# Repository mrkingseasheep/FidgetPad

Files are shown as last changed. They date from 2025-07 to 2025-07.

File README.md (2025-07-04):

# FidgetPad V2.1

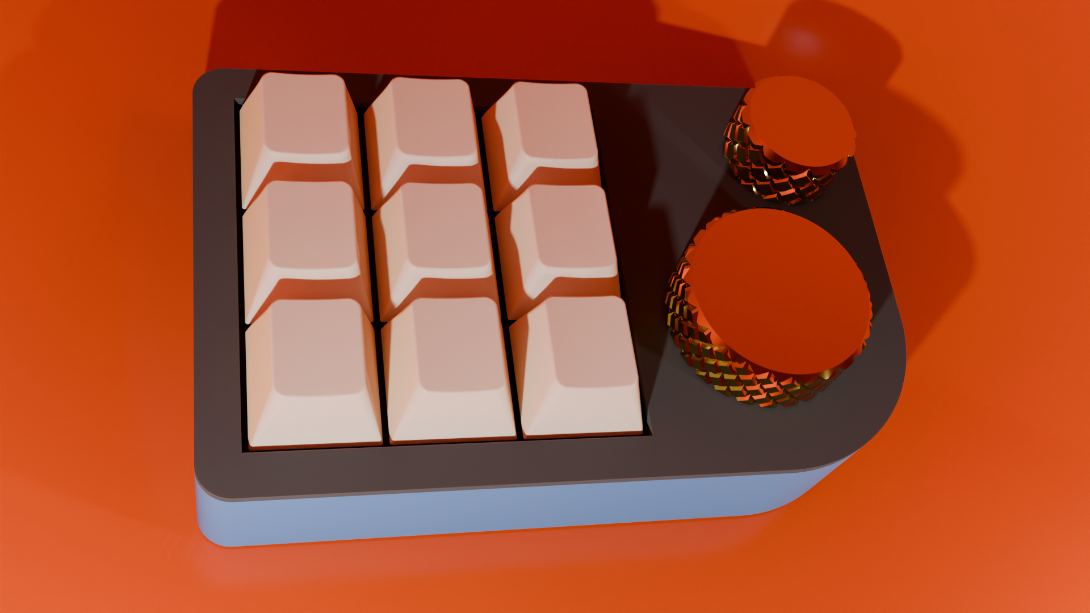
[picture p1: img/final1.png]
Render 1


Keyboards are flat. Flat is boring. Why not add some turny things?

This is a 3x3 macropad with 2 rotary encoders that originally had an OLED screen before I realized that I could trade it in for a 3x3 keyboard instead of a 1x3 row.
It's meant to supplement my normal shitty keyboard which lacks a volume knob, something that I sorely miss.
Btw the git commit history is so empty because I had some large .blend files in my last repo that I just couldn't get rid of (so GitHub didn't let me push) :P

## BOM

| Item | QNT |
| --- | --- |
| MX Style Switchs | 9 |
| Keycaps | 9 |
| 1N4148 Diode | 9 |
| EC11 Encoders | 2 |
| XIAO RP2040 | 1 |
| M3 Screws | 2 |
| M3 Heat Insert | 2 |
| PCB | 1 |
| Case | 1 |

## Images

It took a comical amount of time for me to realize that my schematic could be neat. Don't look at V1. Also turns out I didn't need pullup resistors on every single pin. Neat!
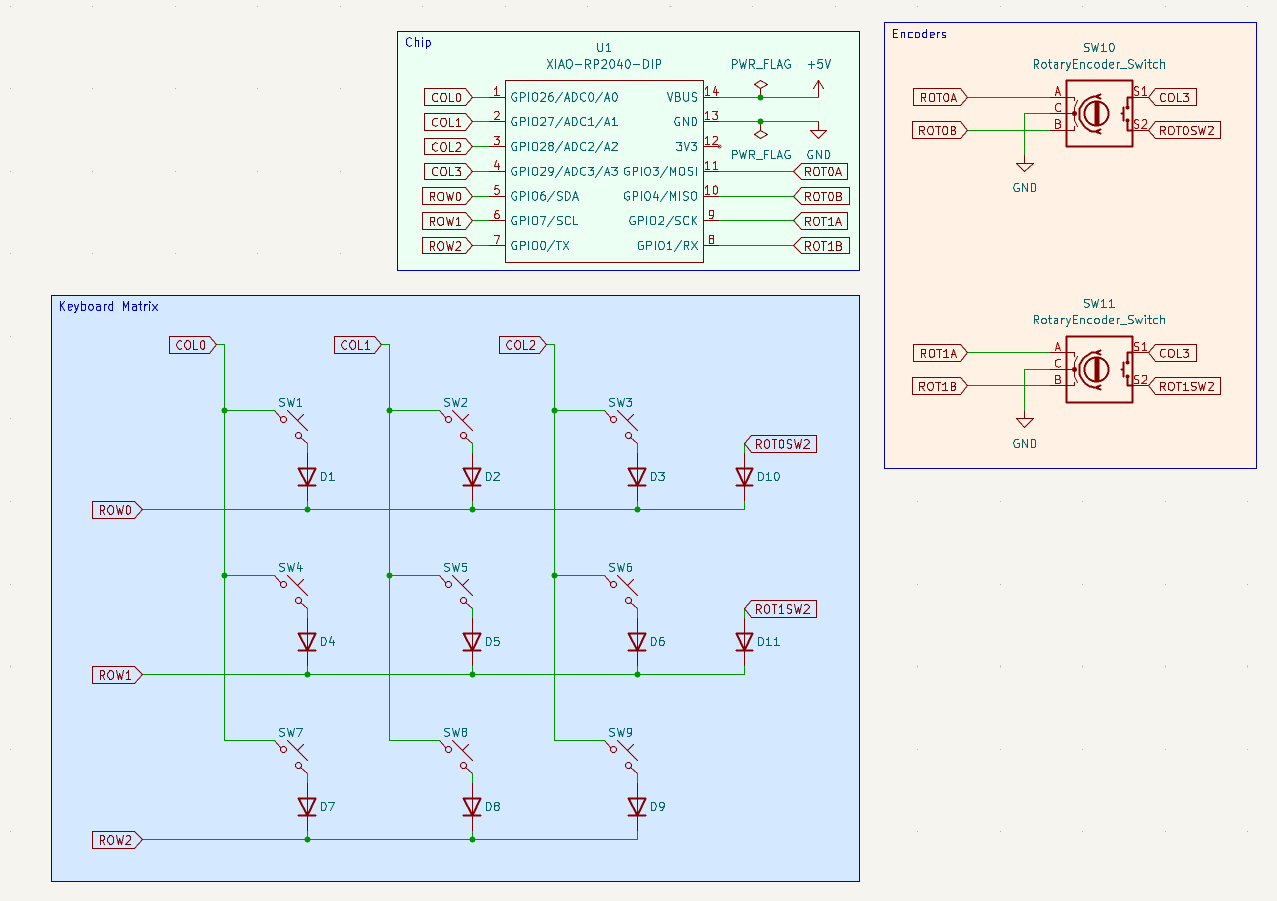
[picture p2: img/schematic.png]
Schematic


There are breakout pins for GND, +5V and +3V3 but I'm not sure if I want to use them. I put them there just in case I wanted to add some jank LEDs at any point in the future.
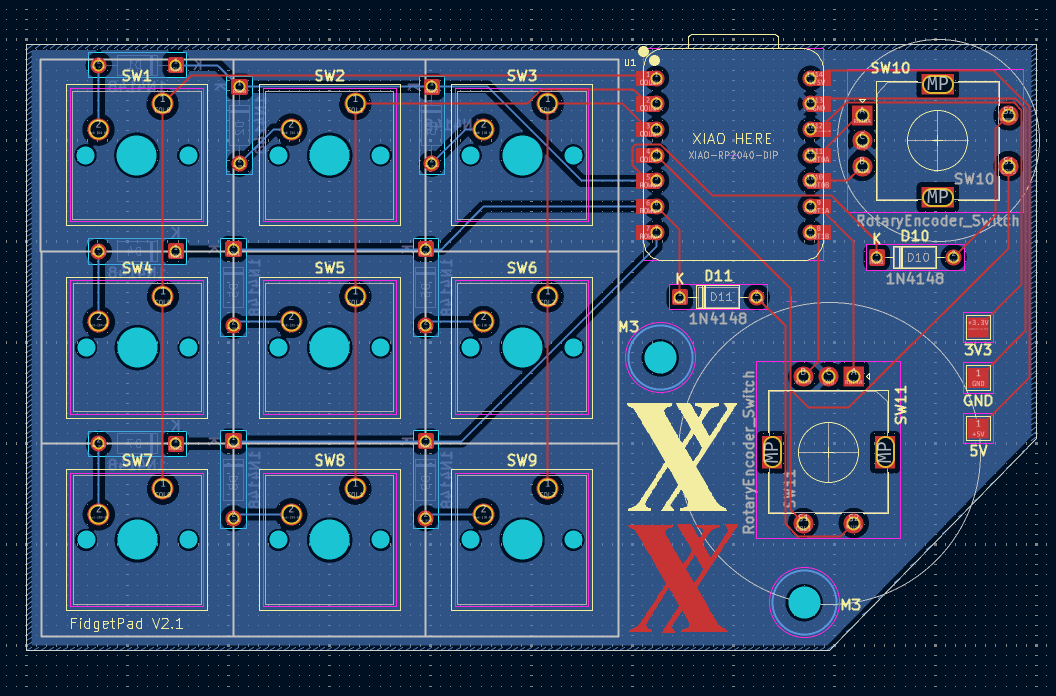
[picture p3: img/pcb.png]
PCB


My 3D models disappeared :<
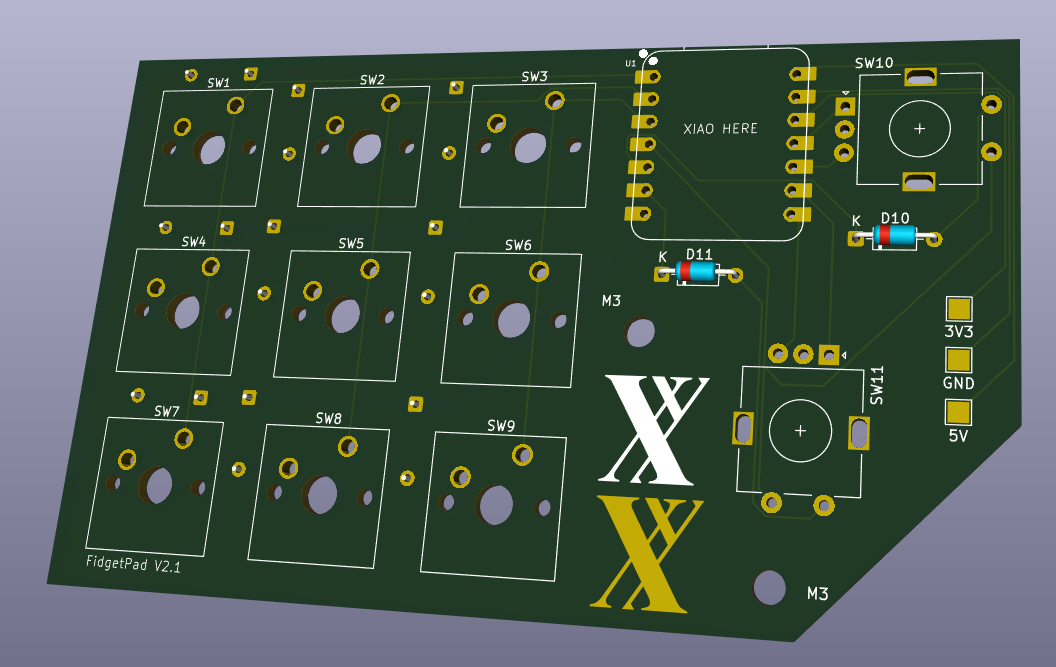
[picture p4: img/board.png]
Board


The PCB attaches to the case with 2 M3 screws. The lid should hopefully work without any screws.
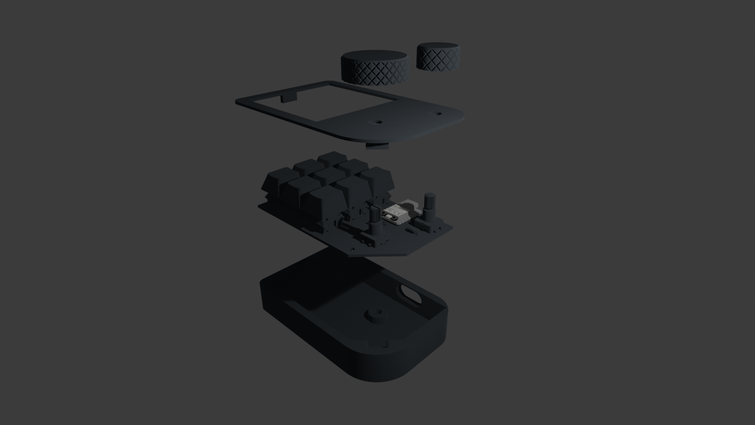
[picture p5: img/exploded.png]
Exploded


wow grayscale, how captivating.
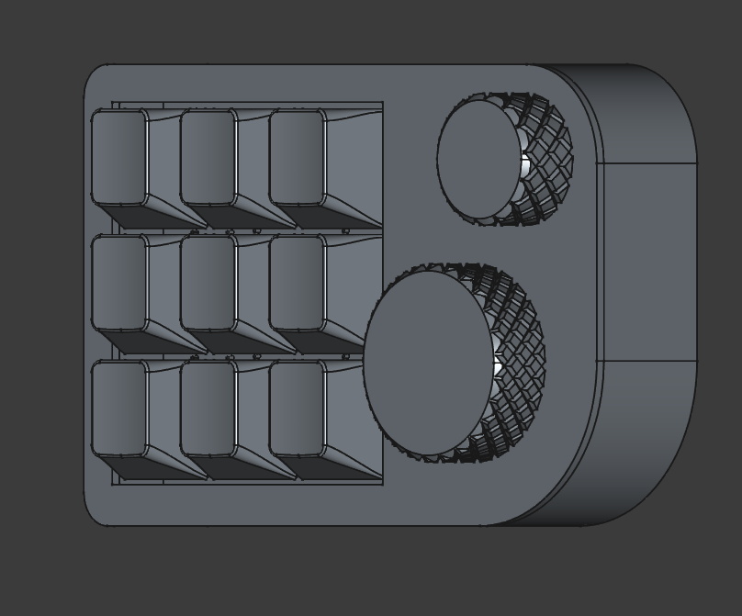
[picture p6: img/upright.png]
Upright


Blender is hard.
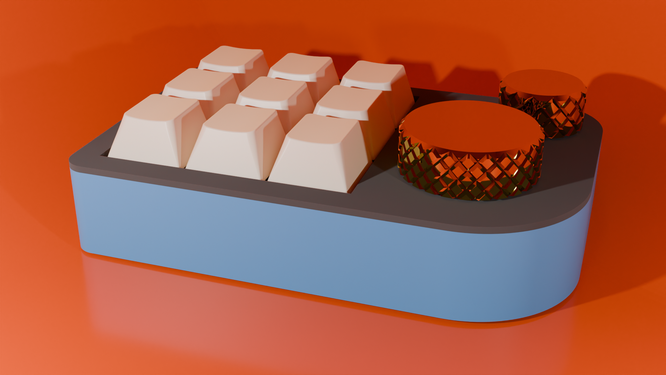
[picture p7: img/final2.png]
Render 2


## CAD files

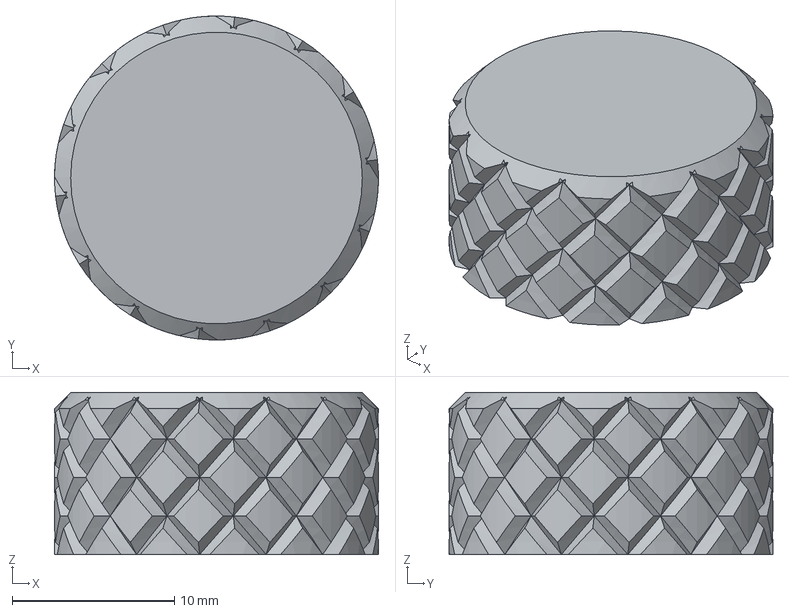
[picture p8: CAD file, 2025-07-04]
Production/SmallKnob.step
20.0 x 20.0 x 10.0 mm

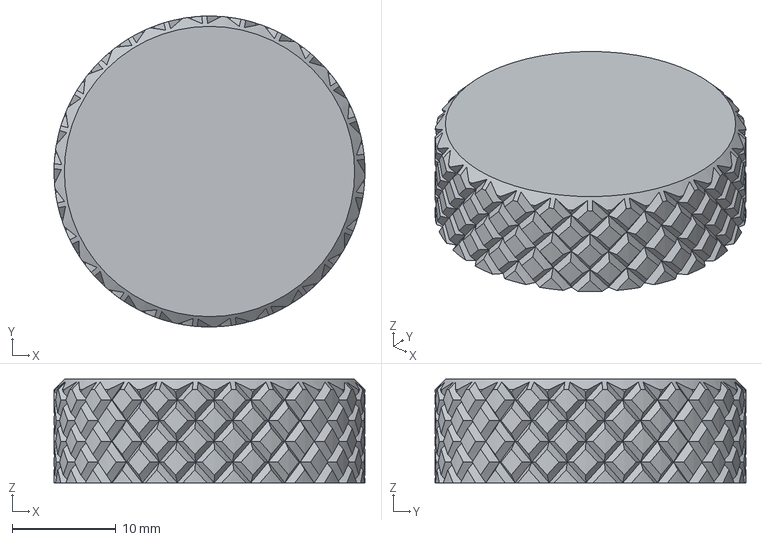
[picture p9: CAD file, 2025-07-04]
Production/LargeKnob.step
30.0 x 30.0 x 10.0 mm

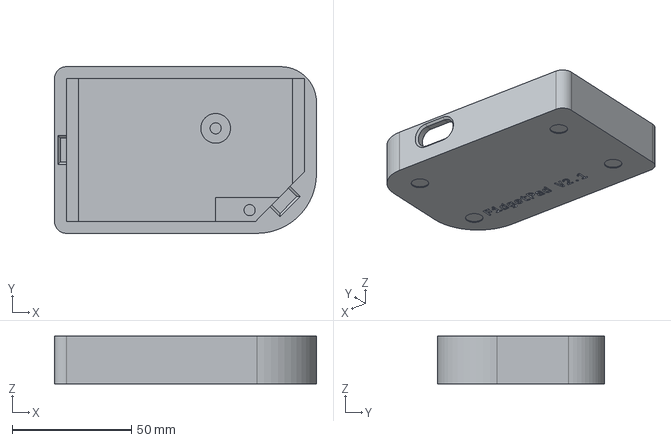
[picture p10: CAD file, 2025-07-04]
Production/Bottom.step
110.0 x 70.0 x 20.0 mm

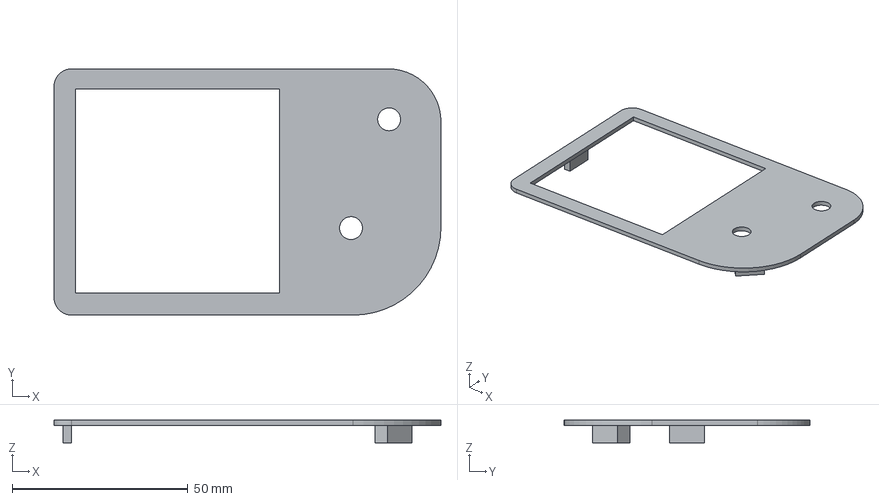
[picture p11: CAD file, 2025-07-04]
Production/Top.step
110.0 x 70.0 x 6.50 mm

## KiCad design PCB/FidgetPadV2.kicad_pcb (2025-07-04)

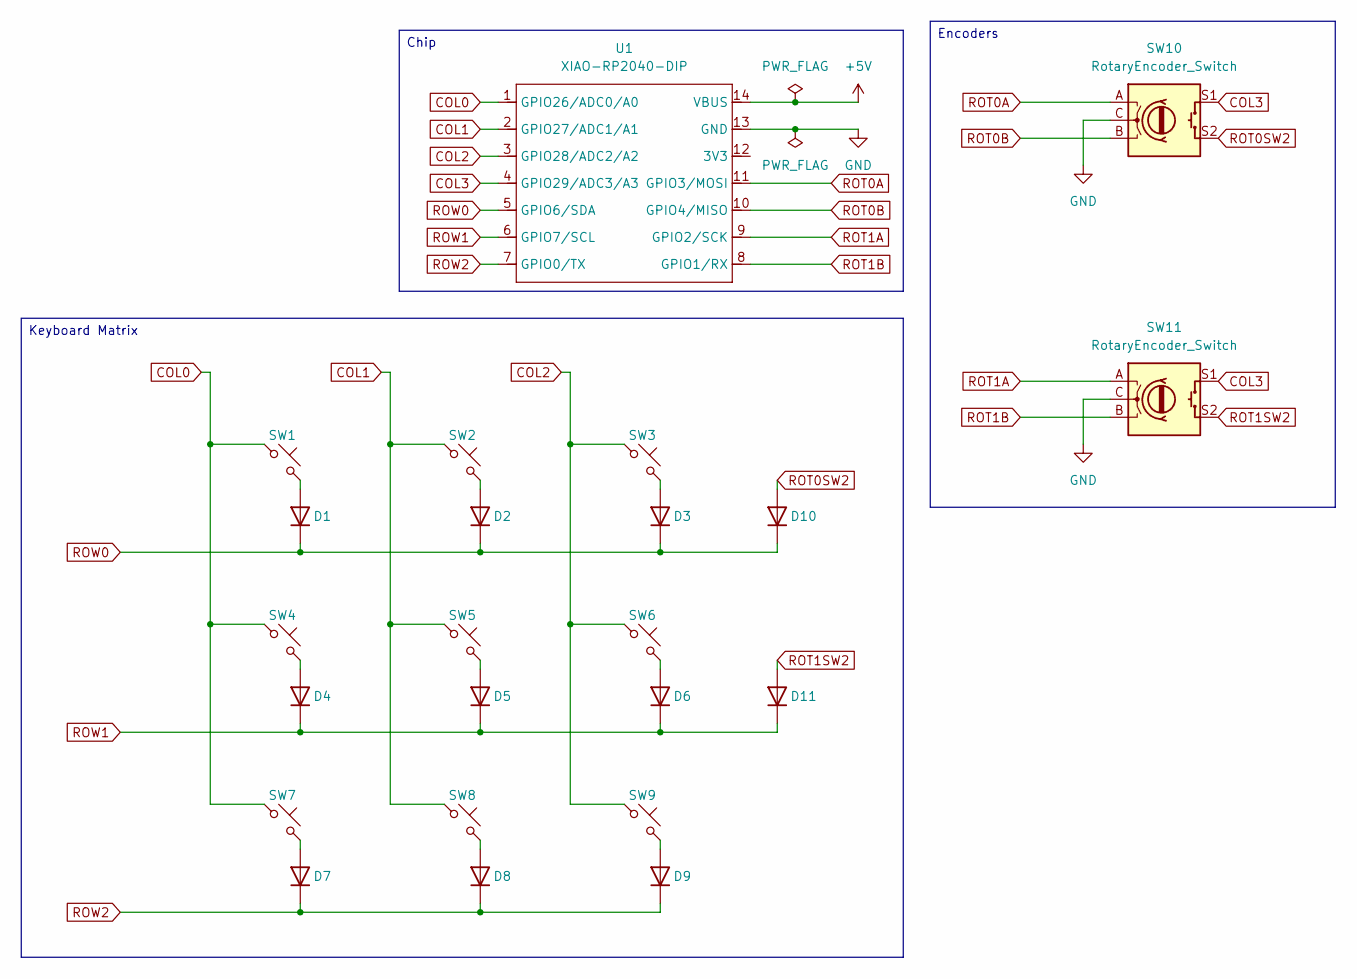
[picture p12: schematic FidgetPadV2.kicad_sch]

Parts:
D1, D2, D3, D4, D5, D6, D7, D8, D9, D10, D11: 1N4148; D_DO-35_SOD27_P7.62mm_Horizontal
SW1, SW2, SW3, SW4, SW5, SW6, SW7, SW8, SW9: SW_Push_45deg; SW_Cherry_MX_1.00u_PCB
SW10, SW11: RotaryEncoder_Switch; RotaryEncoder_Alps_EC11E-Switch_Vertical_H20mm
U1: XIAO-RP2040-DIP

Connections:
+5V: U1.14 (VBUS); also elsewhere on the board
COL0: SW1.1, SW4.1, SW7.1, U1.1 (GPIO26/ADC0/A0)
COL1: SW2.1, SW5.1, SW8.1, U1.2 (GPIO27/ADC1/A1)
COL2: SW3.1, SW6.1, SW9.1, U1.3 (GPIO28/ADC2/A2)
COL3: SW10.S1, SW11.S1, U1.4 (GPIO29/ADC3/A3)
GND: SW10.C, SW11.C, U1.13 (GND); also elsewhere on the board
unnamed: D1.2 (A), SW1.2
unnamed: D2.2 (A), SW2.2
unnamed: D3.2 (A), SW3.2
unnamed: D4.2 (A), SW4.2
unnamed: D5.2 (A), SW5.2
unnamed: D6.2 (A), SW6.2
unnamed: D7.2 (A), SW7.2
unnamed: D8.2 (A), SW8.2
unnamed: D9.2 (A), SW9.2
ROT0A: SW10.A, U1.11 (GPIO3/MOSI)
ROT0B: SW10.B, U1.10 (GPIO4/MISO)
ROT0SW2: D10.2 (A), SW10.S2
ROT1A: SW11.A, U1.9 (GPIO2/SCK)
ROT1B: SW11.B, U1.8 (GPIO1/RX)
ROT1SW2: D11.2 (A), SW11.S2
ROW0: D1.1 (K), D2.1 (K), D3.1 (K), D10.1 (K), U1.5 (GPIO6/SDA)
ROW1: D4.1 (K), D5.1 (K), D6.1 (K), D11.1 (K), U1.6 (GPIO7/SCL)
ROW2: D7.1 (K), D8.1 (K), D9.1 (K), U1.7 (GPIO0/TX)

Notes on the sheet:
Keyboard Matrix
Chip
Encoders

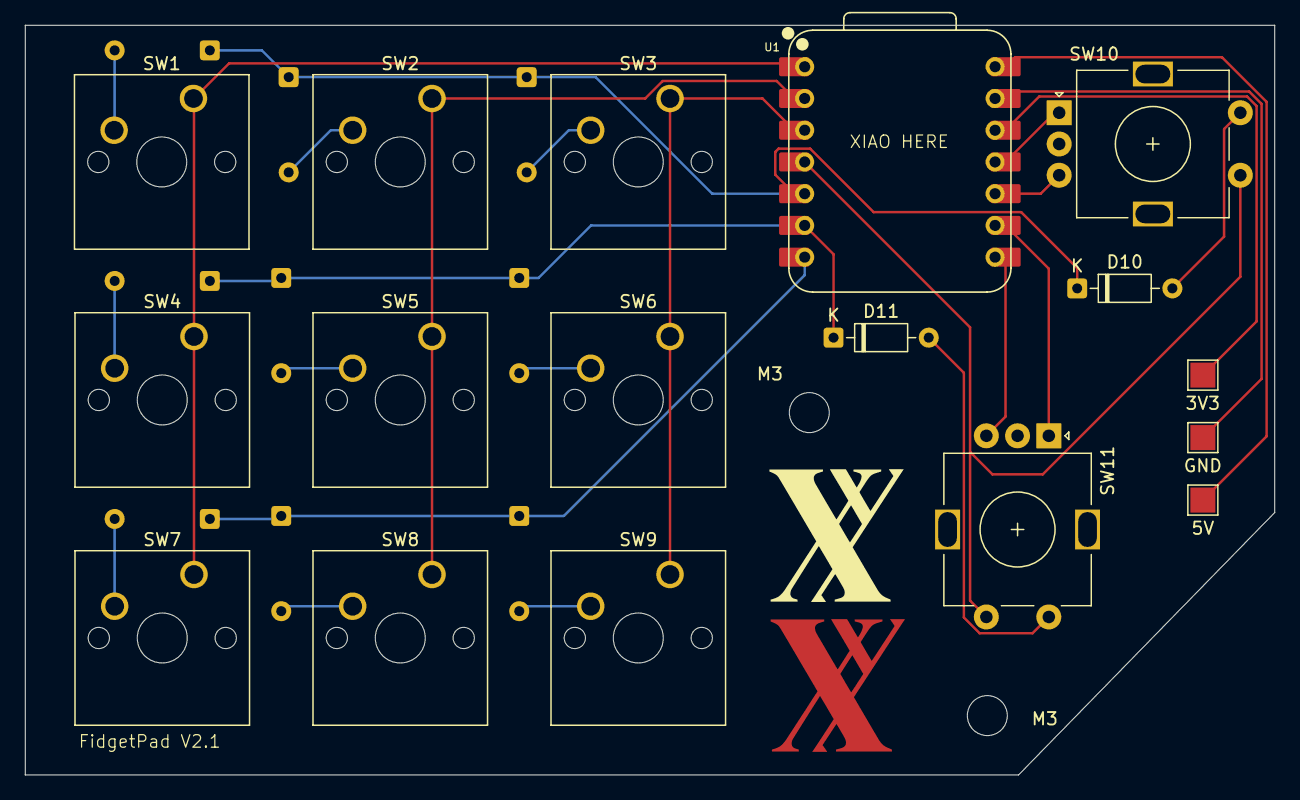
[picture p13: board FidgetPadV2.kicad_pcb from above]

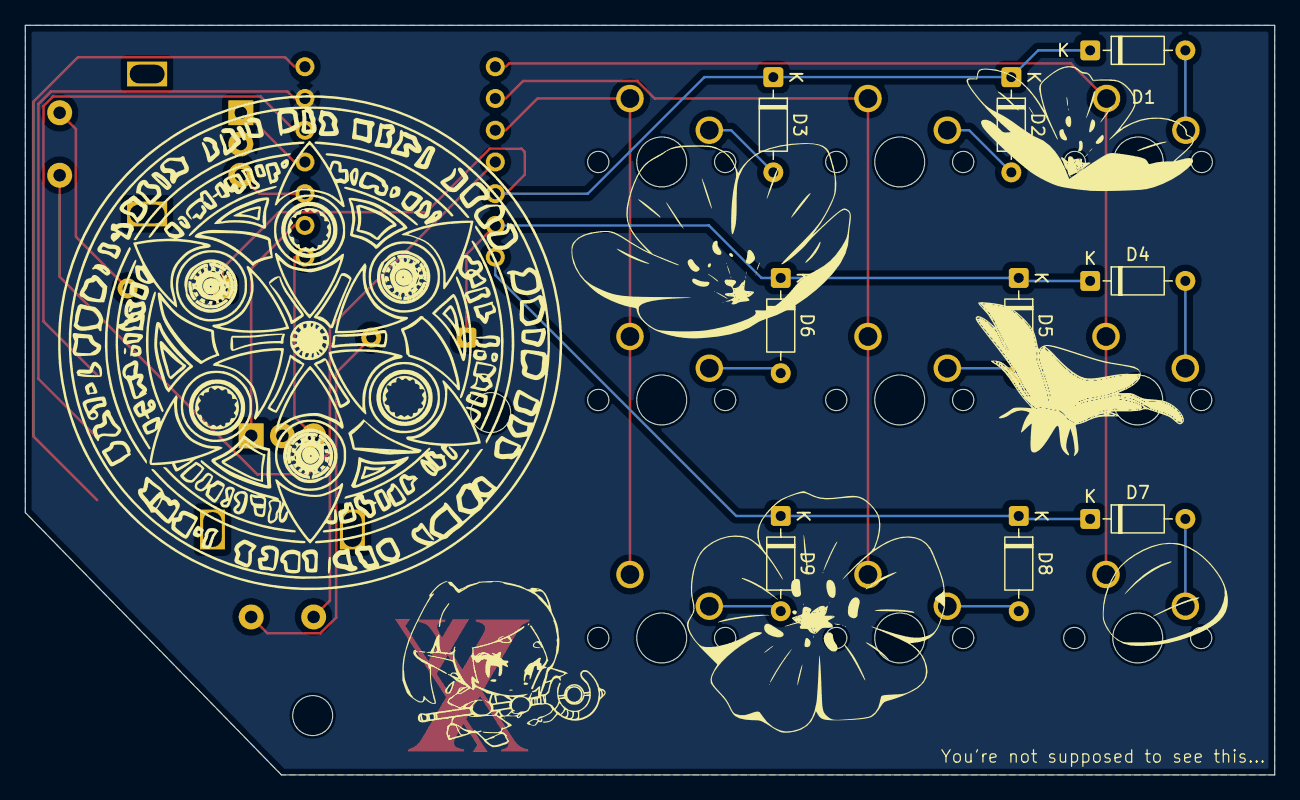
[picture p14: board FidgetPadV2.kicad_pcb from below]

Board: 2 copper layers, 100.0 x 60.0 mm, 28 parts (9 on the bottom side), 24 nets.

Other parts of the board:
3V3, 5V: TestPoint_Pad_2.0x2.0mm
GND: TestPoint_Pad_2.0x2.0mm
M3, M3#2: MountingHole_3.2mm_M3

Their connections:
+5V: 5V.1; also elsewhere on the board
GND: GND.1; also elsewhere on the board
